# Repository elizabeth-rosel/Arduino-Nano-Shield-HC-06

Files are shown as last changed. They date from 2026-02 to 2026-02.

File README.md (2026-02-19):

# HC-06 Module Adapter for Arduino Nano IO Shield

An open-source hardware adapter board to interface the HC-06 Bluetooth module to
the Arduino Nano via an I/O expansion shield.

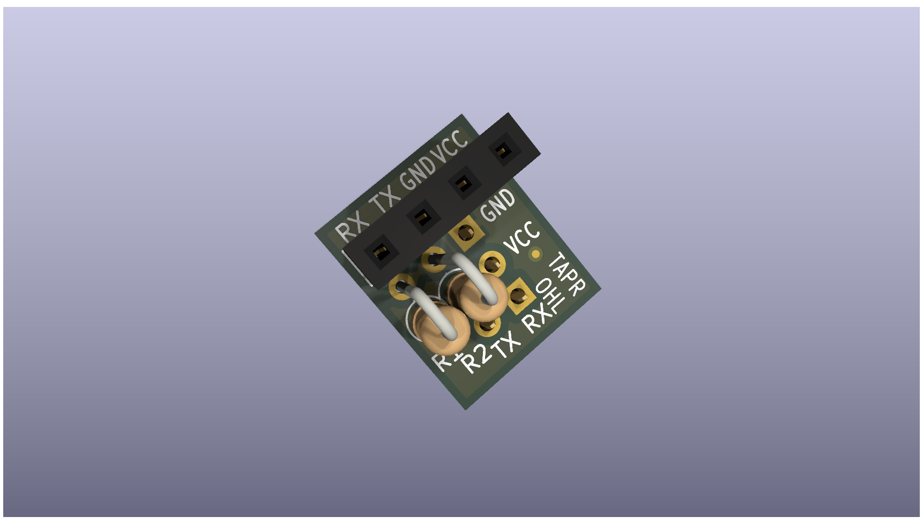
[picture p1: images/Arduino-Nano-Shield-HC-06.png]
The PCB preview


## About

This was initially made to personally facilitate an logic circuits and design
class, where I condensed the adapter circuit for UART communication between the
HC-06 and the Nano. It is just a simple resistor divider to translate from the
Nano's TX to the HC-06's RX pin, as the HC-06 only operates on 3.3V logic level.

This is a very compact design, designed to be as minimally intrusive on the Nano IO shield as possible. This can also be implemented using a 4x4 perforated prototype board of pitch 2.54mm!

The bottom female pins are designed to slot onto the shield's three-row breakout pins, where the top row is ground, middle is 5V, and bottom rows are data/GPIO.

You may also program other GPIO pins to be the Nano's UART interface, apart from the dedicated ones at PD0 and PD1.

Note: The image shown below is an earlier design prototype.

The actual assembled PCB with the HC-06 and the Arduino Nano IO shield

## List of Materials

| Designator | Footprint / Value | Amount |
| --- | --- | --- |
| J1, J2 | 01x02 pin socket with 2.54mm pitch | 2 |
| J3 | 01x04 pin socket with 2.54mm pitch | 1 |
| R1 | 1/4W 2K resistor | 1 |
| R2 | 1/4W 1K resistor | 1 |

## Assembly

Solder in order of smallest to biggest:

1. R1, R2
2. J1, J2
3. J3

### Notes

- J3 may be substituted with two 01x02 pin sockets with 2.54mm pitch.
- You may use a spare pin header to align the pin sockets correctly when assembling.

## License

This is licensed under the [TAPR Open Hardware License](http://www.tapr.org/OHL).

On the board, this is abbreviated as `TAPR OHL`

© Elizabeth Rosel 2025-2026

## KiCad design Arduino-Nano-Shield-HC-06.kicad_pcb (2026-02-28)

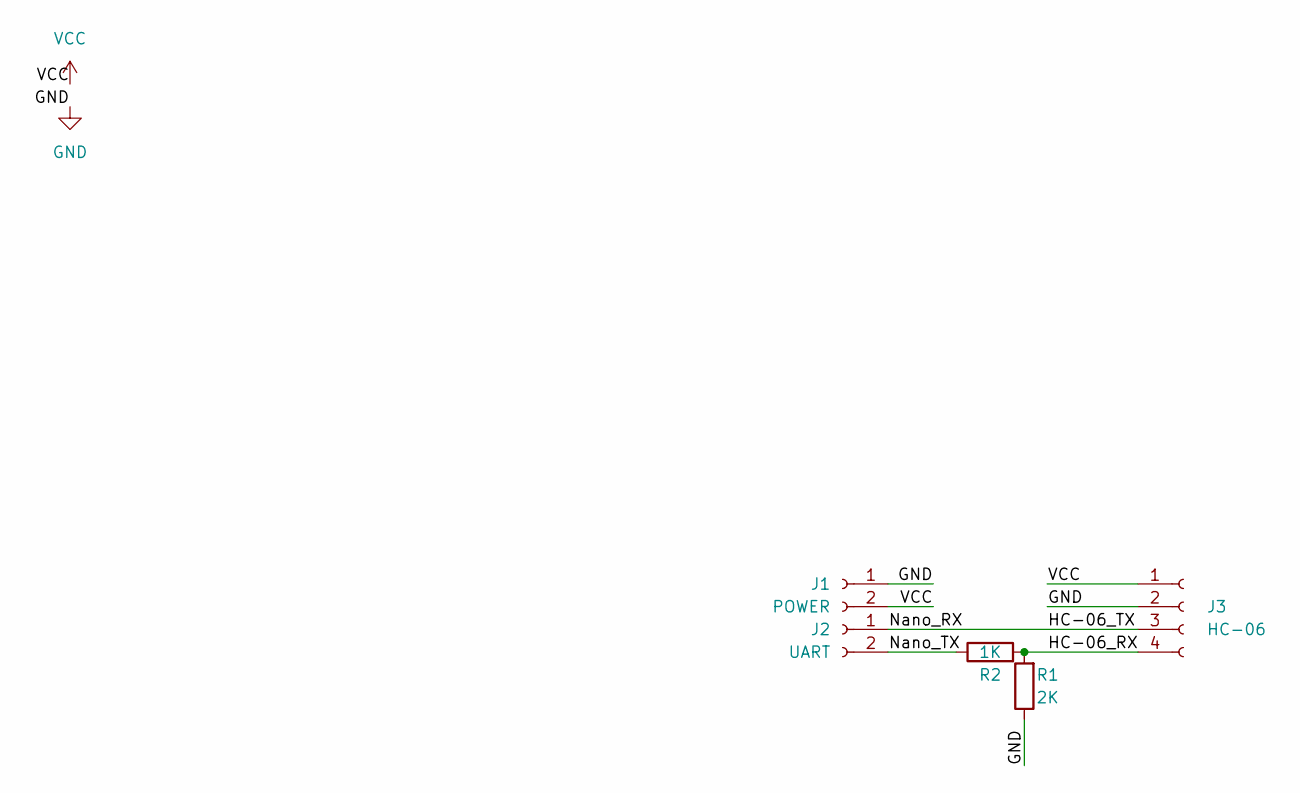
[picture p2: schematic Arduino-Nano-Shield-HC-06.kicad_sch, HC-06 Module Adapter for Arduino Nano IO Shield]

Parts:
J1: POWER; PinSocket_1x02_P2.54mm_Vertical
J2: UART; PinSocket_1x02_P2.54mm_Vertical
J3: HC-06; PinSocket_1x04_P2.54mm_Vertical
R1: 2K; R_Axial_DIN0207_L6.3mm_D2.5mm_P2.54mm_Vertical
R2: 1K; R_Axial_DIN0207_L6.3mm_D2.5mm_P2.54mm_Vertical

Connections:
/HC-06_RX: J3.4, R1.2, R2.2
/HC-06_TX: J2.1, J3.3
/Nano_TX: J2.2, R2.1
GND: J1.1, J3.2, R1.1
VCC: J1.2, J3.1

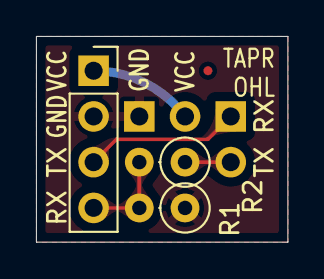
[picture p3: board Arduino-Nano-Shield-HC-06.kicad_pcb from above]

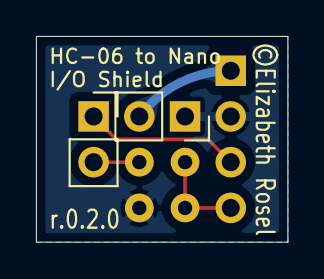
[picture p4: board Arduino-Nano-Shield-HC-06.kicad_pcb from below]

Board: 2 copper layers, 14.0 x 11.4 mm, 5 parts (2 on the bottom side), 5 nets.
